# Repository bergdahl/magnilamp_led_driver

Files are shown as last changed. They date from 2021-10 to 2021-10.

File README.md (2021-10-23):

# magnilamp_led_driver

This is a modification of the Velleman _VTLLAMP1W_ 6W LEDmagnifying glass lamp - https://www.velleman.eu/products/view/?id=380108. 
The modification should also be possible with the 10W successor _WTLLAMP1WN_. 

> Please start this project by cutting off the mains plug so you can't accidently plug it into mains again!

It is powered by 12V and uses a constant current LED driver to drive 24 1W LED's placed on 8 aluminium PCB's.

Gerber files for the PCB's can be found in the Gerber folder, design files for EAGLE can be found in the pcb folder, and design files for Fusion360 for the optional mounting ring can be found in the cad folder.

# LED driver board

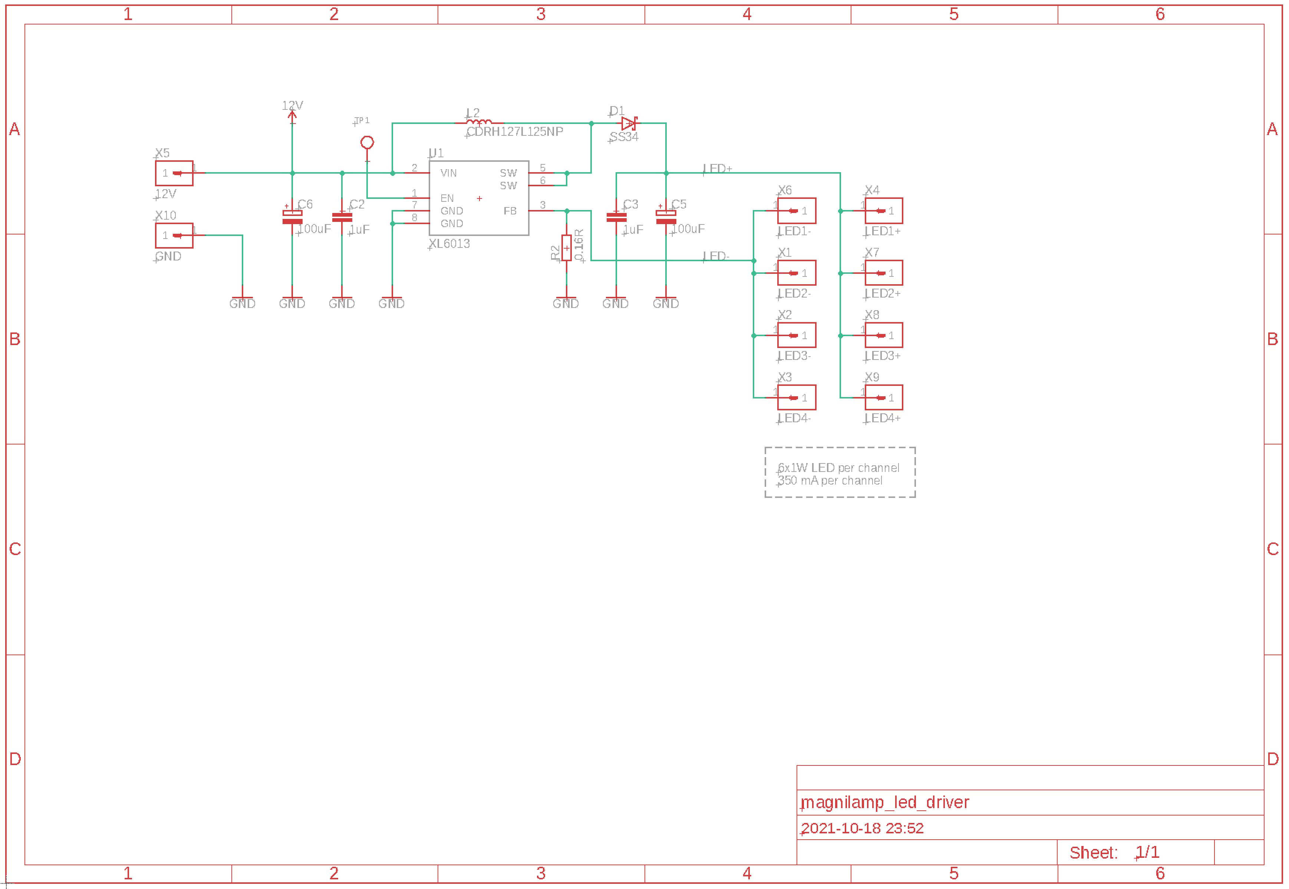
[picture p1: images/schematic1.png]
LED driver board schematic


LED driver board

The LED driver is based on the XLSEMI XL6013 Boost LED driver. 

# LED board

The LED boards are designed to be drop-in replacement of the orginal LED boards.

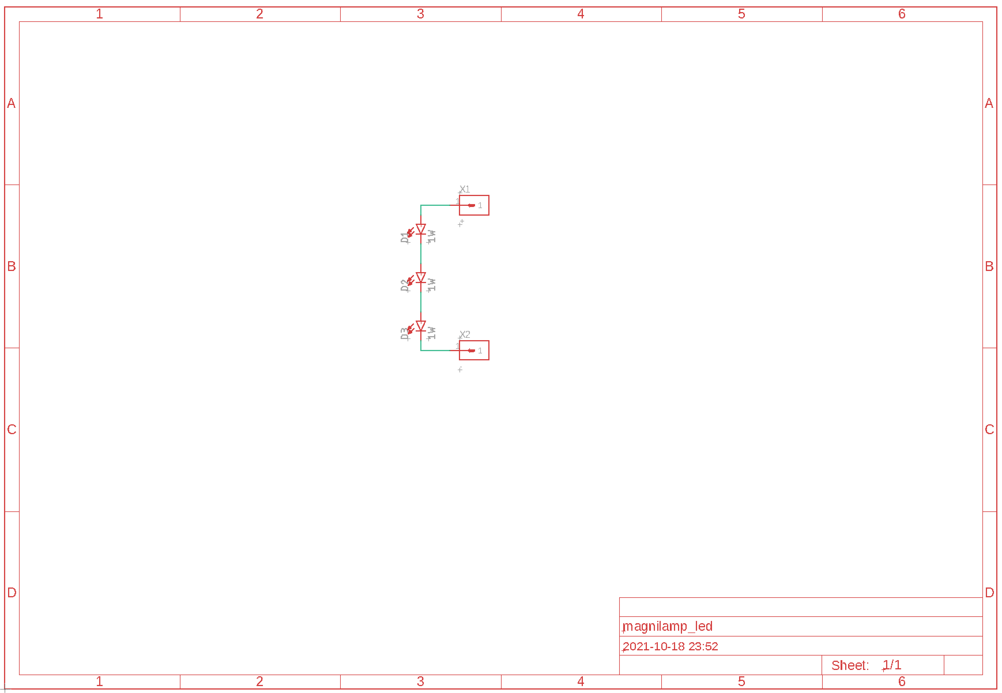
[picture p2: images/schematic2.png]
LED board schematic


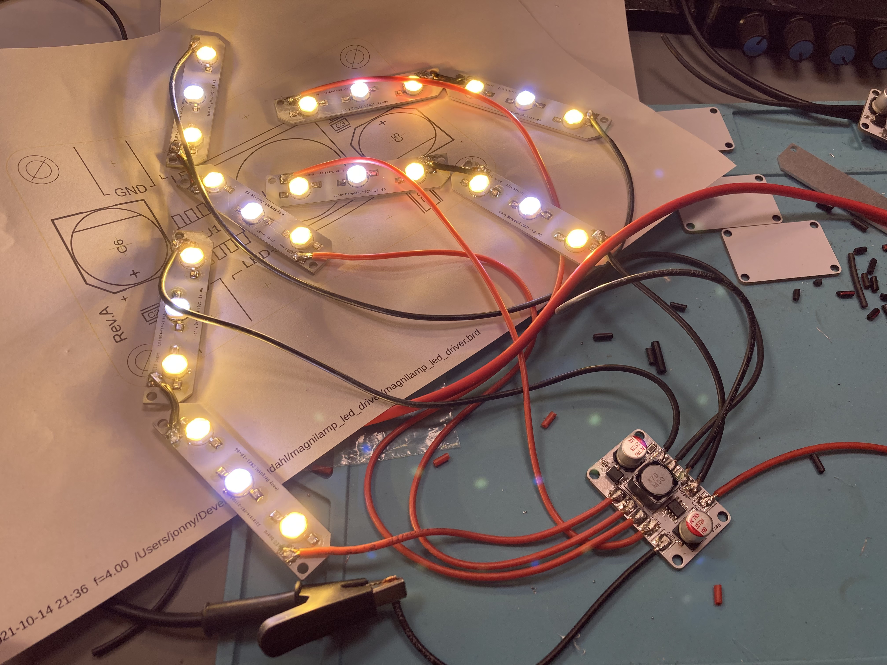
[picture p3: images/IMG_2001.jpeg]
LED board


# Mounting hardware

I designed a replacement 3D printable mounting ring. If you don't have a 3D printer, you can instead modify the original, and make cutouts for the new LED lighting. 

I tried to use PETG, but it turned out to be too brittle so I ended out printing it in clear PLA instead. Also, I really hate the stringing PETG. In the end it turned out the lamp does not get hot, so PLA is perfectly fine for this.

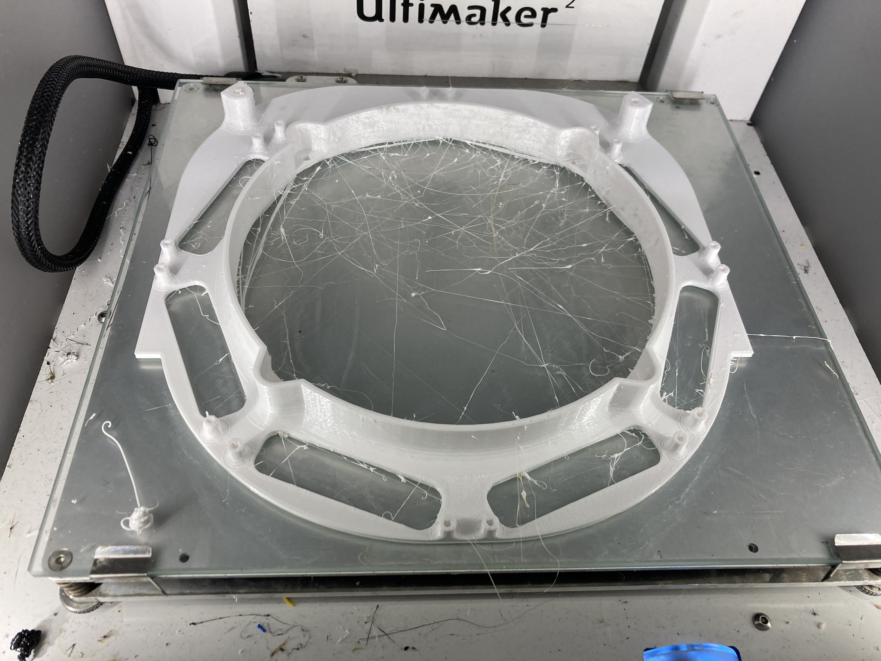
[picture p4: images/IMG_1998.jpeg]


# Assembly

I am reusing the 240V cable for power, using blue for 12V and brown for GND. I used double sided tape to fasten the LED driver in the lamp. 

The LED PCB's should be soldered together 2 by 2, and the resulting 2 LED "strips" soldered to the LED board.

Finish up by connecting the old mains wires to 12V and GND of the LED driver. 

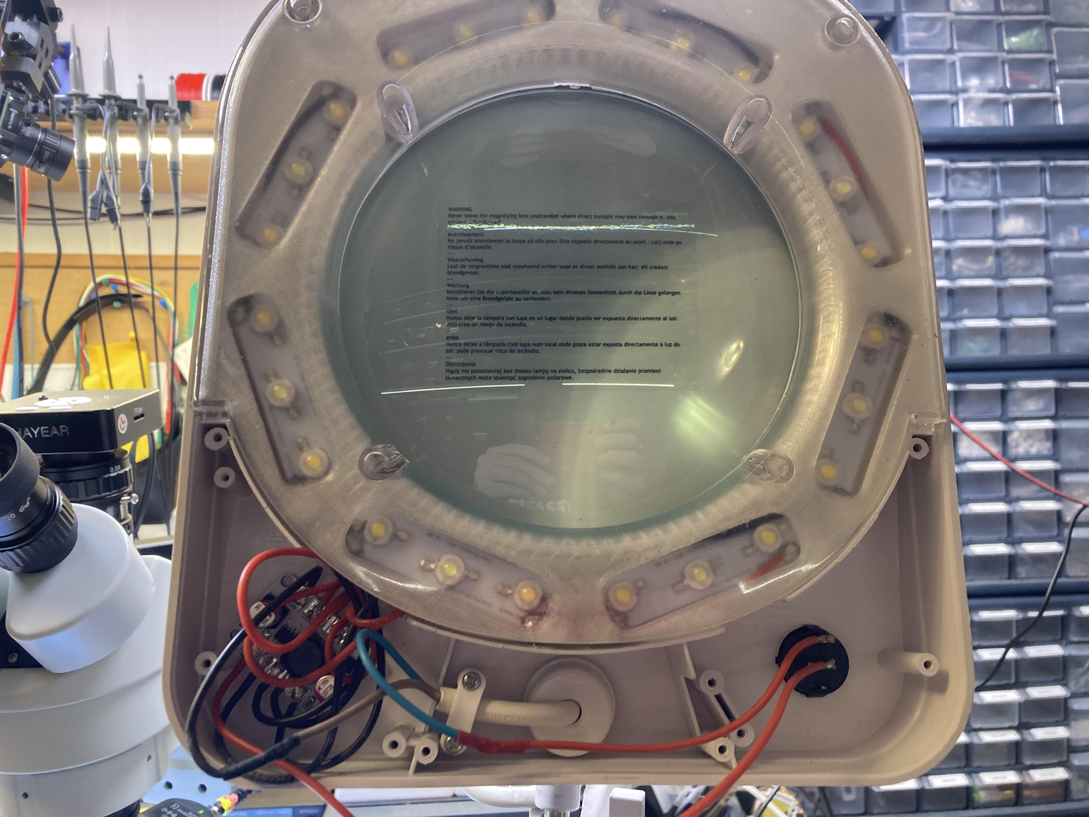
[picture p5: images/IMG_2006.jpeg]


# Final product.

I actually had to lower the current to the LED's as it was way to bright. I run it at 15W now instead of 24W and my lux meter tells me it outputs 7000 lux. That is plenty bright, and the life time of the LED's will be almost infinite.

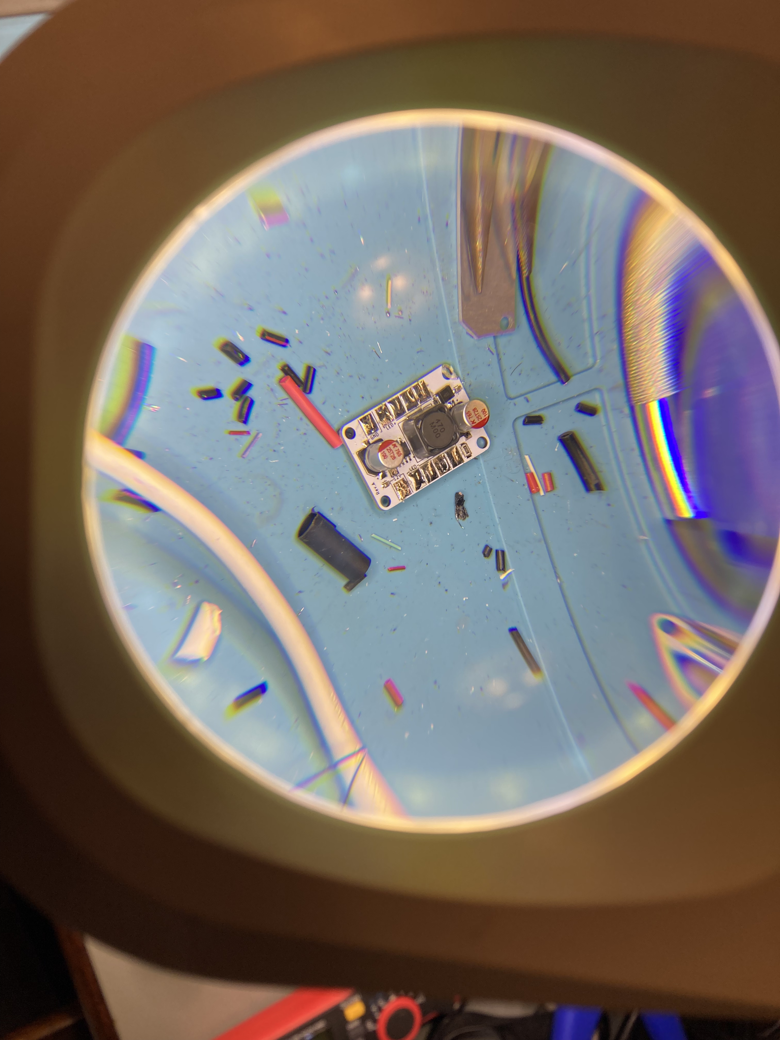
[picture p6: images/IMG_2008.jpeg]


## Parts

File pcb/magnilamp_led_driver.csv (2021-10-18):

Part | Value | Device | Package | Description
C2 | 1uF | CAPC0603 | C0603
C3 | 1uF | CAPC0603 | C0603
C5 | 100uF | CAP-KEMETKN | KEMET-KN
C6 | 100uF | CAP-KEMETKN | KEMET-KN
D1 | SS34 | DIODE-SCHOTTKYDO-214AC | DO-214AC | 304020028
L2 | CDRH127L125NP | IND-SUMIDACDRH127L125 | SUMIDA-CDRH127L125
R2 | 0.16R | RESISTOR1206 | R1206
TP1 |  | TESTPOINTPAD | TESTPOINT_PAD_2MM | Test Point
U1 | XL6013 | XLSEMI-XL6013 | SOP8
X1 | LED2- | SOLDERPAD4X5 | SOLDERPAD-4X5
X2 | LED3- | SOLDERPAD4X5 | SOLDERPAD-4X5
X3 | LED4- | SOLDERPAD4X5 | SOLDERPAD-4X5
X4 | LED1+ | SOLDERPAD4X5 | SOLDERPAD-4X5
X5 | 12V | SOLDERPAD4X5 | SOLDERPAD-4X5
X6 | LED1- | SOLDERPAD4X5 | SOLDERPAD-4X5
X7 | LED2+ | SOLDERPAD4X5 | SOLDERPAD-4X5
X8 | LED3+ | SOLDERPAD4X5 | SOLDERPAD-4X5
X9 | LED4+ | SOLDERPAD4X5 | SOLDERPAD-4X5
X10 | GND | SOLDERPAD4X5 | SOLDERPAD-4X5

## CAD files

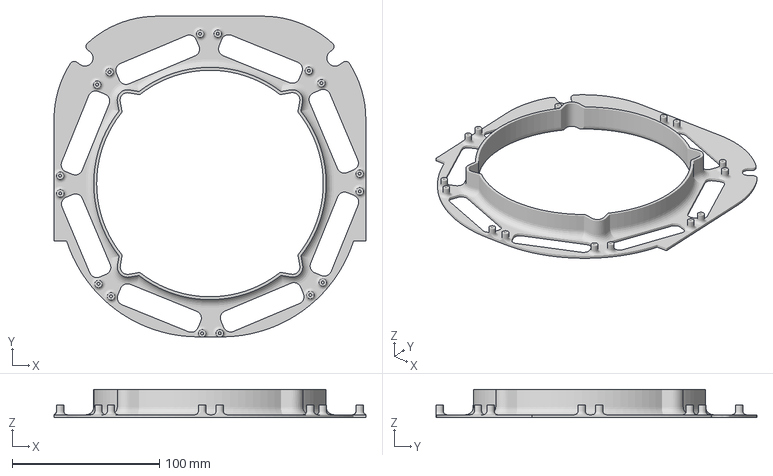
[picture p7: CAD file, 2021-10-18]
cad/Magnifier Lamp LED Mount.3mf
212.1 x 218.0 x 19.3 mm

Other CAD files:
cad/Magnifier Lamp LED Mount.f3d

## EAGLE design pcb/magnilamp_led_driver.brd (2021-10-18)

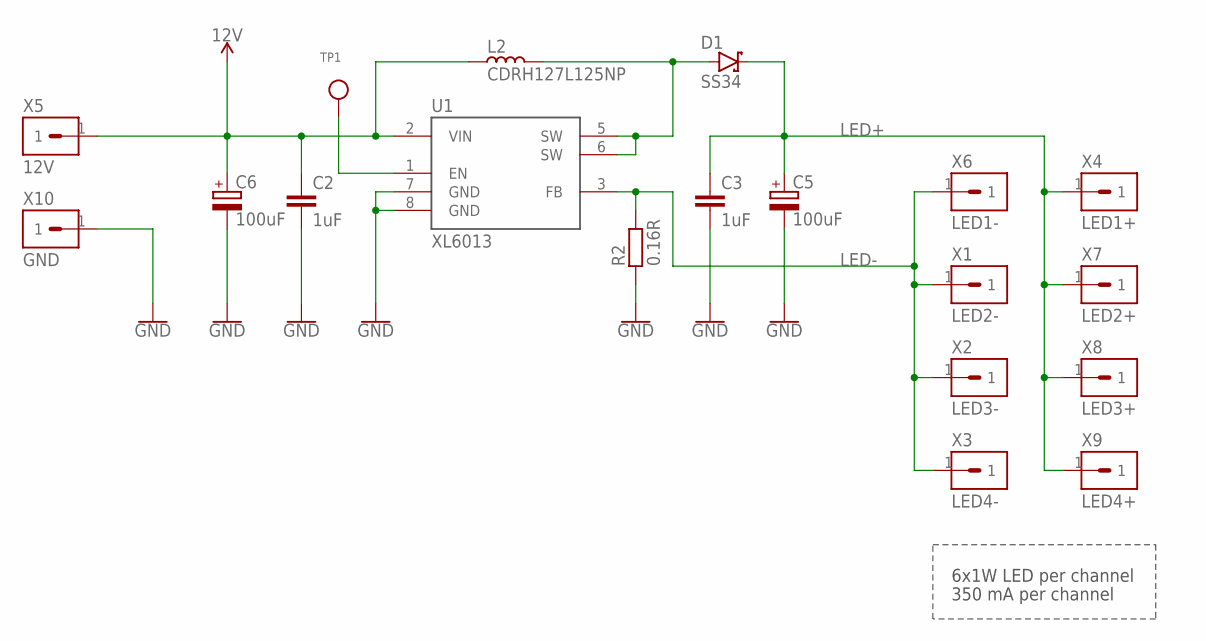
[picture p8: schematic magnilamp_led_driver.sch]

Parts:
C2, C3: 1uF; C0603
C5, C6: 100uF; KEMET-KN
D1: SS34; DO-214AC
L2: CDRH127L125NP; SUMIDA-CDRH127L125
R2: 0.16R; R1206
TP1: TESTPOINTPAD; TESTPOINT_PAD_2MM
U1: XL6013; SOP8
X1: LED2-; SOLDERPAD-4X5
X2: LED3-; SOLDERPAD-4X5
X3: LED4-; SOLDERPAD-4X5
X4: LED1+; SOLDERPAD-4X5
X5: 12V; SOLDERPAD-4X5
X6: LED1-; SOLDERPAD-4X5
X7: LED2+; SOLDERPAD-4X5
X8: LED3+; SOLDERPAD-4X5
X9: LED4+; SOLDERPAD-4X5
X10: GND; SOLDERPAD-4X5

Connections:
12V: C2.1, C6.+, L2.1, U1.2 (VIN), X5.1
GND: C2.2, C3.2, C5.-, C6.-, R2.1, U1.7 (GND), U1.8 (GND), X10.1
LED+: C3.1, C5.+, D1.C, X4.1, X7.1, X8.1, X9.1
LED-: R2.2, U1.3 (FB), X1.1, X2.1, X3.1, X6.1
unnamed: TP1.P$1, U1.1 (EN)
unnamed: D1.A, L2.2, U1.5 (SW), U1.6 (SW)

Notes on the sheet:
6x1W LED per channel
350 mA per channel

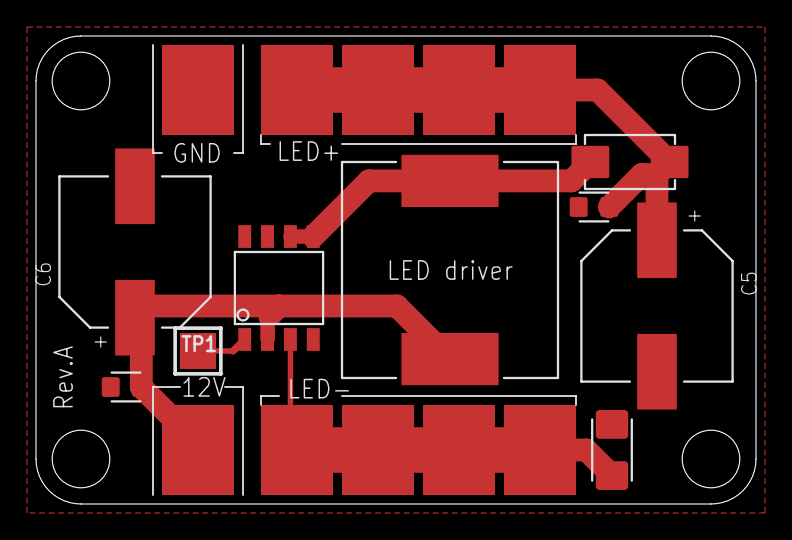
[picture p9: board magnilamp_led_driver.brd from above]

Board: 2 copper layers, 40.0 x 26.0 mm, 19 parts (0 on the bottom side), 6 nets.

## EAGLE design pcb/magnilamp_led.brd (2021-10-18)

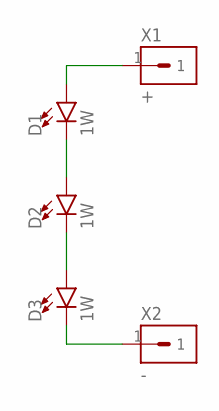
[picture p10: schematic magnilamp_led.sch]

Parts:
D1, D2, D3: 1W; LED_1W
X1: +; SOLDERPAD-4X5
X2: -; SOLDERPAD-4X5

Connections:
unnamed: D1.A, X1.1
unnamed: D1.C, D2.A
unnamed: D2.C, D3.A
unnamed: D3.C, X2.1

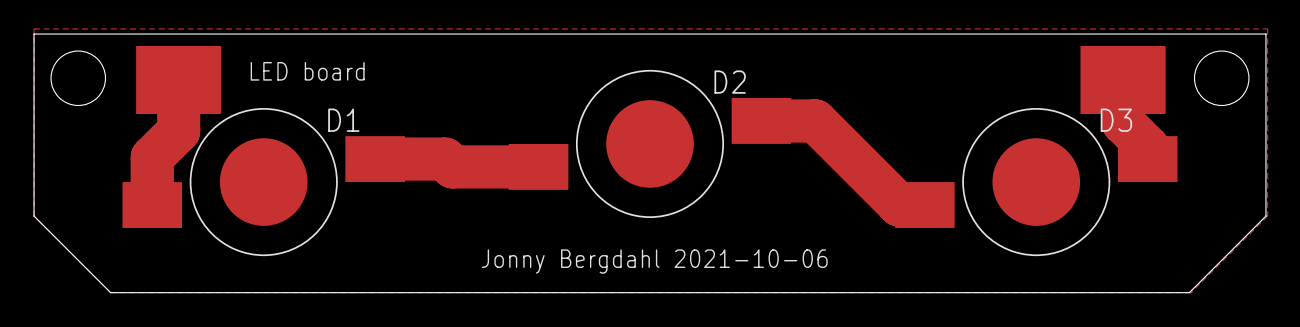
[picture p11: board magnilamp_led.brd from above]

Board: 2 copper layers, 72.4 x 15.2 mm, 5 parts (0 on the bottom side), 4 nets.
